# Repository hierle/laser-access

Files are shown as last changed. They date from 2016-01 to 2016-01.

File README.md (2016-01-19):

# laser-access

An access system for a laser cutter (or any other electric system), based on Arduino, ESP8266 Wifi and NFC reader and member cards.
Easy update of tag database via Wifi link to a central user db. This is running just fine for a while here at Fablab Munich :)

* [./eagle](https://github.com/hierle/laser-access/eagle/) &nbsp;&nbsp;&nbsp;&nbsp;&nbsp; PCB (eagle) files for custom shield
* [./housing](https://github.com/hierle/laser-access/housing/) &nbsp;&nbsp;&nbsp; DXF drawing for laser cut housing
* [./laser_access](https://github.com/hierle/laser-access/laser_access/) &nbsp; Arduino software

The software is running on an Arduino Mega 2560, packed with a "shield" (eagle files included),
holding breakout modules for RTC, NFC, Wifi (ESP8862-1), I2C-EEPROM and TFT touch display.

It's reading NFC (Mifare) cards dropped in, comparing the serial to a database in internal eeprom,
granting access to known serials only. If the tag serial number is found in eeprom database, then
- the 230V main relais of the laser cutter is turned on
- user name and phone number (both stored on the card) are displayed

If the dedicated "update card" is seen, the database (of allowed card serial numbers) is downloaded from a (Raspberry Pi) Wifi access point.

Internal 4k eeprom of the Mega board allows for up to 1000 users, external EEPROM holds up to 64kBytes log events.

Libraries used:

- https://github.com/adafruit/Adafruit_NFCShield_I2C
- https://github.com/adafruit/Adafruit-GFX-Library
- https://github.com/adafruit/Adafruit_ILI9341
- https://github.com/adafruit/Adafruit_STMPE610

Have fun :)

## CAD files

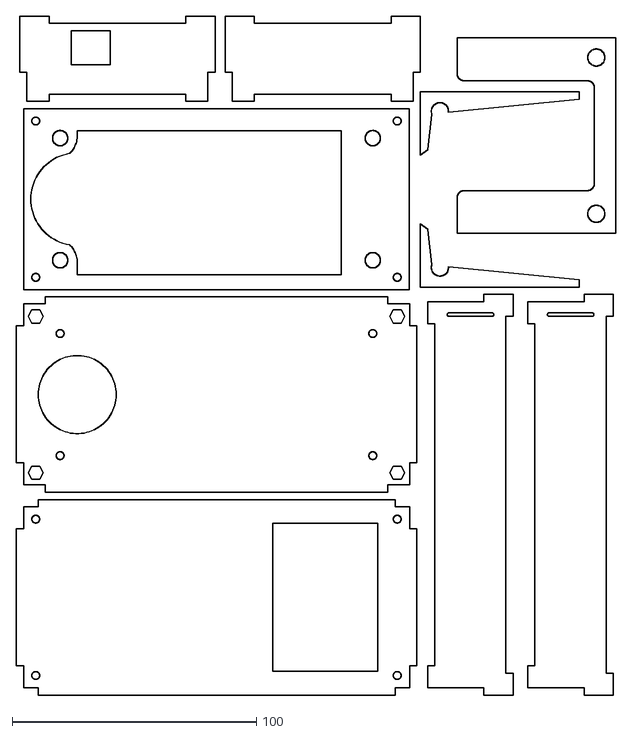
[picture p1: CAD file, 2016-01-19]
housing/laser-access-housing.dxf
245.5 x 278.0

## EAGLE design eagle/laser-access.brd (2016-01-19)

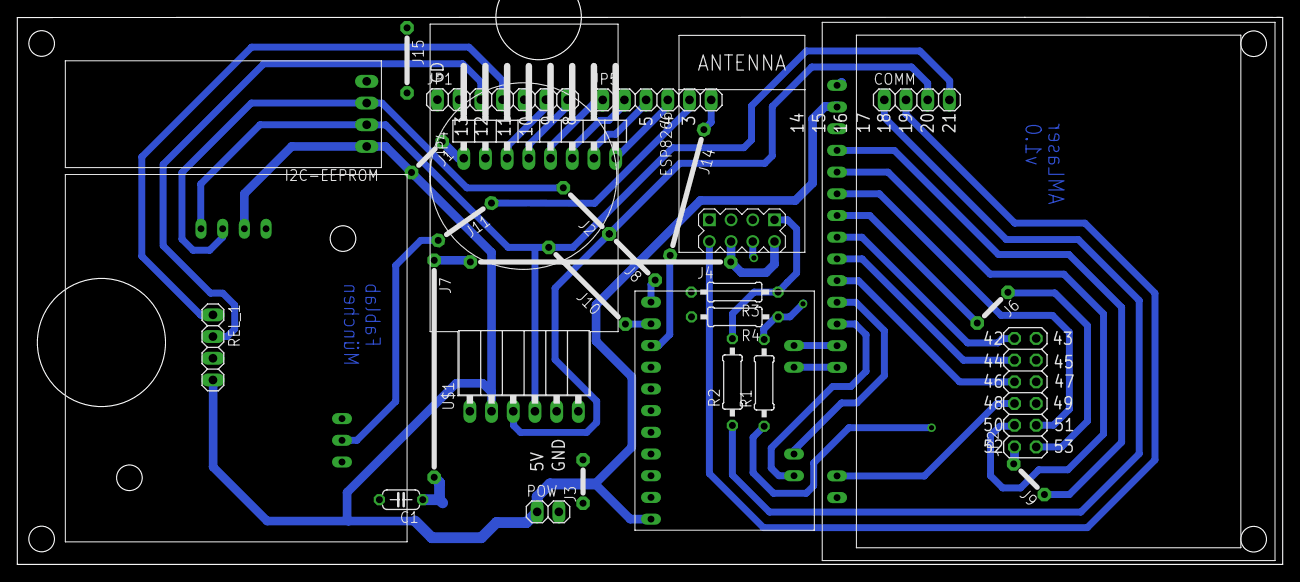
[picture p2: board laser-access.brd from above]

Board: 2 copper layers, 148.1 x 64.0 mm, 31 parts (1 on the bottom side), 32 nets.

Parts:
C1: C050-024X044
COMM: 1X04
ESP8266: WIRELESS-WIFI-ESP-01
I2C-EEPROM: I2C-EEPROM
IC2: LD117AS33TR; SOT223
J1, J3, J6, J9: J5MM; 05
J2, J8, J11, J15: J7MM; 07
J4: J30MM; 30
J7: J25MM; 25
J10: J12MM; 12
J14: J15MM; 15
JP1: 1X07
JP2: 2X06
JP4: 1X08/90
JP5: 1X06
POW: 1X02
R1, R2: 10k; 0207/10
R3, R4: 20k; 0207/10
REL_1: 1X04
U$1: I2C-RTC
U$3: TFT-2.4-SPI; TFT-SPI-2.4
U$4: I2C-NFC-V3
U$6: R-TOUCH

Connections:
42: JP2.12, U$3.DC
43: JP2.11, R1.1
44: JP2.10, U$3.RST
46: JP2.8, U$3.LITE
48: JP2.6, U$3.CCS
50: JP2.4, U$3.MISO
51: JP2.3, U$3.MOSI
52: J9.1, J9.2, JP2.2, U$3.CLK
53: J6.1, J6.2, JP2.1, U$3.CS
+3V3: C1.1, ESP8266.B2, ESP8266.D2, IC2.4, J4.1, J4.2, J7.1, J7.2
+5V: I2C-EEPROM.+5V, IC2.3, J1.1, J1.2, JP4.1, POW.1, REL_1.4, U$1.+5V, U$3.+5V, U$4.+5V, U$6.+5V
D2: J14.1, J14.2, JP5.6, U$6.IRQ
D3: J11.1, J11.2, JP5.5, U$4.IRQ
D4: JP4.8, JP5.4
D5: JP4.7, JP5.3
D6: JP4.6, JP5.2
D7: JP4.5, JP5.1
D8: JP1.7, JP4.4
D9: JP1.6, JP4.3
D11: JP1.4, REL_1.1
D12: JP1.3, REL_1.2
ESPRST: ESP8266.C2, R1.2, R4.1
ESP_RX: ESP8266.D1, R2.2, R3.1
GND: C1.2, ESP8266.A1, I2C-EEPROM.GND, IC2.1, J3.1, J3.2, J15.1, J15.2, JP1.1, JP4.2, POW.2, R3.2, R4.2, REL_1.3, U$1.GND, U$3.GND, U$4.GND, U$4.GND2, U$6.GND, U$6.MODE
RXD1: COMM.2, ESP8266.A2
SCL: COMM.4, I2C-EEPROM.SCL, J10.1, J10.2, U$1.SCL, U$4.SCL, U$6.SCL
SDA: COMM.3, I2C-EEPROM.SDA, J2.1, J2.2, J8.1, J8.2, U$1.SDA, U$4.SDA, U$6.SDA
TXD1: COMM.1, R2.1
X+: U$3.X+, U$6.X+
X-: U$3.X-, U$6.X-
Y+: U$3.Y+, U$6.Y+
Y-: U$3.Y-, U$6.Y-

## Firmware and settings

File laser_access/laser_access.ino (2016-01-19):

// 
// Name:      laser_access.ino
// Version:   0.1.4-github
// Date:      20160119
// Author:    A.Hierle <github@hierle.com>
// Purpose:   fablab laser access control
// Platform:  arduino mega2560


#include "laser_access.h"

#include <Wire.h>   // RTC and RTC-eeprom
#include <EEPROM.h> // internal eeprom
#include <SPI.h>    // SPI for TFT & SD card
#include <SD.h>     // SD card
#include <Adafruit_STMPE610.h>
#include <Adafruit_NFCShield_I2C.h>
#include <Adafruit_GFX_AS.h>
#include <Adafruit_ILI9341_AS.h>

#include <avr/pgmspace.h> // PROGMEM

time_t now;
time_t then;
//int wifi_status=0;
int enable=0;  // privileged enable mode: default off
time_t enable_start; // start enable mode
time_t power_start; // start ready mode
time_t dim_start; // start light/dim
time_t sense_last;

int counter=0;
int mode = 0;
int dim = 0;
unsigned long key_start=0;
uint8_t nfcid[]  = { 0, 0, 0, 0, 0, 0, 0 };
uint8_t lastid[] = { 0, 0, 0, 0 };
//unsigned long nfctag;
user_t user;
char command[64];
int sense[] = { -1, -1, -1, -1, -1, -1 };

uint8_t keya[6] = { 0xFF, 0xFF, 0xFF, 0xFF, 0xFF, 0xFF }; // NFC card default key
uint8_t keyf[6] = { 0x11, 0x22, 0x33, 0x44, 0x55, 0x66 }; // NFC card custom key, CHANGE!!!


// TFT
Adafruit_ILI9341_AS tft = Adafruit_ILI9341_AS(TFT_CS, TFT_DC, -1);
// Touch
Adafruit_STMPE610 touch = Adafruit_STMPE610();
// NFC
Adafruit_NFCShield_I2C nfc(NFC_IRQ, NFC_RESET);


//
// setup, running once, after reset
//
void setup() {
  
  // set default mode: power off
  mode = MODE_OFF;

  // power relais : LOW => ON , HIGH => OFF
  pinMode(PIN_POWER, OUTPUT);
  digitalWrite(PIN_POWER,HIGH);

  // esp reset line
  pinMode(PIN_ESP_RESET, OUTPUT);

  // init sense pins as input
  pinMode(SENSE_0, INPUT);
  pinMode(SENSE_1, INPUT);
  pinMode(SENSE_2, INPUT);
  pinMode(SENSE_3, INPUT);
  pinMode(SENSE_4, INPUT);

  // init I2C
  Wire.begin();

  write_log("booting");

  // init serial PC
  //Serial.begin(9600);
  Serial.begin(115200);
  Serial.println();
  Serial.println(F("booting ..."));
  
  Serial.print(F("init ESP8266..."));
  // init serial to wifi module
  //Serial1.begin(9600);
  Serial1.begin(115200);
  // 500?1000
  //Serial1.setTimeout(1000);
  // reset
  reset_wifi();
  
  Serial.println(F("ok"));

  // get time from DS3232 RTC
  get_time(&now);

  // dim off tft backlight
  analogWrite(PIN_TFT,200);
  get_time(&dim_start);
  dim=1;

  // start tft, blank black
  //tft.begin();
  tft.init();
  //tft.fillScreen(ILI9341_BLACK);
  tft.fillScreen(ILI9341_WHITE);

  if (! touch.begin(I2C_TOUCH_ADDR)) {
    Serial.println(F("touch controller not found!"));
    while(1);
  }
  //Serial.println(F("Waiting for touch sense"));


  // NFC
  Serial.print(F("init NFC controller..."));
  nfc.begin();
  //nfc.setPassiveActivationRetries(0x01);
  nfc.setPassiveActivationRetries(0x05);
  nfc.SAMConfig();
  Serial.println(F("ok"));

  // default: power OFF
  power_on(0);

  // init finished
  Serial.println(F("boot done!"));


  //
  // ONLY ONCE: set root pw ... has changed anyway :)
  //write_enable_pw("itchyiktestus");
  //
  // ONLY ONCE: set date/time
  //time_t n={22,10,0,2016,1,19};
  //set_time(n);

}
// end of setup



//
// the loop over and over
//
void loop() {


  int i;
  int bytesrec=0;
  int msglen=63;
  char usbmsg[msglen];
  char wifimsg[msglen];
  char buffer[16];
  uint16_t x, y;
  uint8_t z;
  
  memset(usbmsg,0,msglen); 
  memset(wifimsg,0,msglen); 

  // get time from rtc
  get_time(&now);
  // TODO: check for dead rtc ... too many things depend on it

  // update time display, once per minute
  if(now.minute!=then.minute) {
    //get_time(&then);
    memcpy((void *)&then,(void *)&now,sizeof(now));
    print_tft_time();
  }

  // update senses every 5 seconds
  if(mode==MODE_ON) {
    if (time_diff(now,sense_last)>5) {
      print_tft_sense();
      get_time(&sense_last);
    }
  }

  // enable mode expired?
  //if (time_diff(now,enable_start)>ENABLE_TIMEOUT) { enable=0; Serial.println("enable timeout reached ... disabling privileged mode."); }
  if(enable==1) {
    if (time_diff(now,enable_start)>ENABLE_TIMEOUT) {
      enable=0; 
      Serial.println(F("enable timeout reached ... disabling privileged mode."));
      write_log("enable off (timeout)");
    }
  }

  // dim timeout  
  if(dim==1) {
    if (time_diff(now,dim_start)>DIM_TIMEOUT) {
      analogWrite(PIN_TFT,10);
      dim=0;
    }
  }
  
  // touched
  if (touch.touched()) {
    analogWrite(PIN_TFT,200);
    get_time(&dim_start);
    dim=1;
    /**
    // read x & y & z;
    while (! touch.bufferEmpty()) {
      touch.readData(&x, &y, &z);
    }
    **/
    touch.writeRegister8(STMPE_INT_STA, 0xFF); // reset all ints
    delay(10);
  }

  if(mode==MODE_ON) {
    if (time_diff(now,power_start)>CARD_TIMEOUT) {
      mode=MODE_CARD;
      print_tft_power(2);
      //Serial.println(F("card timeout reached, re-validating card."));
    }
  }
  // timeout re-reading card
  if((mode==MODE_ON)||(mode==MODE_CARD)) {
    if (time_diff(now,power_start)>OFF_TIMEOUT) {
      power_on(0);
      Serial.println(F("power off (card timeout)"));
      write_log("power off");
    }
  }
  
  // read NFC tag
  if ((mode == MODE_CARD)||(mode == MODE_OFF)) {
    // nfc card detected?
    uint8_t success = 0;
    uint8_t nfclen;  // length of nfc id

    success = nfc.readPassiveTargetID(PN532_MIFARE_ISO14443A, nfcid, &nfclen);
    if (success) {
      handle_nfc(nfcid);
      //delay(100);
    } // success
    //Serial.println(" failed.");
  } //mode

  
  // serial (USB) from PC/user
  if(Serial.available()) {
    bytesrec = Serial.readBytes(usbmsg,msglen);
    handle_usb(usbmsg);
  }

  // serial from Wifi
  if(Serial1.available()) {
    bytesrec = Serial1.readBytes(wifimsg,msglen);
    handle_wifi(wifimsg);
  }
  
  delay(100);
}
// end of main loop





//
// functions
//


void reset_wifi() {
  // reset esp
  digitalWrite(PIN_ESP_RESET,LOW);
  //delay(350);
  //delay(800);
  delay(2000);
  digitalWrite(PIN_ESP_RESET,HIGH);
  //delay(2000);

  return;
}

//
// import access db via wifi
//
void import_wifi() {
  //
  // TODO: loop thru pages ...
  //
  int msglen=64;
  char msg[msglen];
  int bytesrec=0;
  user_t user;
  tag_t tag;
  char buffer[64];
  tag_t array[100];
  unsigned long id;
  int ac=0;
  int i;
  int page;
  int imported=0;
  String cmd;

  Serial.println(F("importing user db..."));
  write_log("importing user db...");

  tft.fillRect(0, 55, 310, 144, ILI9341_WHITE);

  tft.setTextColor(ILI9341_BLACK);
  tft.setRotation(3);
  sprintf(buffer,"%s","importing user db...");
  tft.drawString(buffer,20,80,4);

  // AT+CIPSTART="TCP","192.168.10.11",80
  //cmd = "AT+CIPSTART=\"TCP\",\"";  
  //cmd += "192.168.10.11";
  //cmd += "\",80";
  cmd = F("AT+CIPSTART=\"TCP\",\"192.168.10.11\",80");

  Serial1.println(cmd);  //send command to device

  delay(1000);  //wait a little while for 'Linked' response - this makes a difference
  if(Serial1.find("CONNECT")) {
    Serial.println(F("connected to server at 192.168.10.11"));
    sprintf(buffer,"%s","connected");
    tft.drawString(buffer,20,110,2);
  }
  else {
    Serial.println(F("'CONNECT' response not received"));
    sprintf(buffer,"%s","could not connect :(");
    tft.drawString(buffer,20,110,2);
  }

  delay(1000);
  
  // sequence ?page=1...10
  cmd = F("GET /cgi-bin/access\?amlaser HTTP/1.1\r\nHost: 192.168.10.11\r\n\r\n");
  Serial1.print(F("AT+CIPSEND="));
  Serial1.println(cmd.length());

  delay(200);

  //if(Serial1.find(">"))    //prompt offered by esp8266
  if(Serial1.find("OK")) {  //prompt offered by esp8266
    Serial.println(F("sending GET request..."));  //a debug message
    sprintf(buffer,"%s","sending GET request...");
    tft.drawString(buffer,20,125,2);
    Serial1.println(cmd);  //this is our http GET request
  }
  else {
    Serial1.println(F("AT+CIPCLOSE"));  //doesn't seem to work here?
    Serial.println(F("no '>' prompt received after AT+CPISEND"));
  }

  while (Serial1.find("ACCESS|")) {
    //if(Serial1.available()) {
    //bytesrec = Serial1.readBytes(msg,msglen);
    memset(msg,0,msglen);
    bytesrec = Serial1.readBytes(msg,10);
      
    sscanf(&msg[2],"%lx",(long *)&id);
    array[ac].b[3] = (id & 0xFF);
    array[ac].b[2] = ((id >> 8) & 0xFF);
    array[ac].b[1] = ((id >> 16) & 0xFF);
    array[ac].b[0] = ((id >> 24) & 0xFF);
    ac++;
  }    

  sprintf(buffer,"%d users received",ac);
  Serial.println(buffer);
  tft.drawString(buffer,20,140,2);
  write_log(buffer);

  for (i=0;i<ac;i++) {
    if(add_tag(array[i])==0) { imported++; }
  }

  sprintf(buffer,"%d new users imported",imported);
  Serial.println(buffer);
  tft.drawString(buffer,20,155,2);

  write_log(buffer);
  
  Serial1.println(F("AT+CIPCLOSE"));  
  delay(250);
  if(Serial1.find("OK")) {
    sprintf(buffer,"%s","connection closed.");
    tft.drawString(buffer,20,170,2);
  }

  //sprintf(buffer,"total: %d users imported",imported);
  //Serial.println(buffer);
  //tft.drawString(buffer,20,170,2);

   delay(3000);
} 
  

// user help (w/ and w/o enable)
void print_help() {
  time_t now;
  int secondsleft=0;
  
  Serial.println("");
  Serial.print(FIRMWARE);
  Serial.print(F(" v"));
  Serial.println(VERSION);
  Serial.println("");
  if(enable==1) {
    get_time(&now);
    secondsleft = ENABLE_TIMEOUT - time_diff(now,enable_start);
    Serial.println(F("available commands (enable mode):"));
    Serial.println("");
    Serial.println(F("addtag <nfctag>          : add nfc tag (4 byte id FFFFFFFF in hex) plus pin"));
    Serial.println(F("chpw <old_pw> <new_pw>   : change enable (privileged) mode password")); 
    Serial.println(F("cleardb                  : wipe out user db in eeprom"));
    Serial.println(F("clearlog                 : wipe out logs"));
    Serial.println(F("date                     : print current date/time"));
    Serial.println(F("deltag <nfctag>          : delete nfc tag (4 byte id FFFFFFFF in hex) (TODO)"));
    Serial.print  (F("disable                  : end enable mode ... "));Serial.print(secondsleft);Serial.println(F(" seconds left"));
    Serial.println(F("import                   : import access db via wifi"));
    Serial.println(F("list                     : list allowed nfc tags"));
    Serial.println(F("log                      : show log entries"));
    Serial.println(F("resetwifi                : reset esp wifi"));
    Serial.println(F("wifi <command>           : send command to wifi module, e.g. AT :)"));
    Serial.println(F("h (or ?)                 : this help"));
    //Serial.println(F("testlog <count>          : test log"));
    Serial.println("");
  }
  else { // free 4 all commands
    Serial.println(F("available commands:"));
    Serial.println("");
    Serial.println(F("h (or ?)                 : this help"));
    Serial.println(F("log                      : list log entries"));
    Serial.println(F("date                     : print current date / time"));
    Serial.println(F("enable <enable pw>       : switch to privileged mode")); 
    Serial.println("");
  }
}  



// handle serial from PC
void handle_usb(char * msg) {
  int i;
  
  // help
  if((msg[0]=='h')||(msg[0]=='?')) { print_help(); return; }
  // date
  if(strncmp(msg,"date",4)==0) { print_date(); return; }
  // log
  if(strncmp(msg,"log",3)==0) { read_log(); return; }
  // switch to enable mode
  if(strncmp(msg,"enable",6)==0) { start_enable(msg); return; }

  // for the rest of the user commmands, we need to be in enable mode
  if(enable!=1) { Serial.println(F("unknown command, try \"help\"")); return; }

  // add tag
  if(strncmp(msg,"addtag",6)==0) { if(add_nfctag(&msg[7])==0) { Serial.println(F("added.")); } return; }
  // change enable password
  if(strncmp(msg,"chpw",4)==0) { Serial.println(F("changing enable password.")); change_enable_pw(msg); return; }
  // clear eeprom user db
  if(strncmp(msg,"cleardb",7)==0) { clear_db(EE_USER); return; }
  // clear logs
  if(strncmp(msg,"clearlog",8)==0) { clear_log(); return; }
  // reset esp wifi
  if(strncmp(msg,"resetwifi",9)==0) { reset_wifi(); return; }
  // import users via wifi
  if(strncmp(msg,"import",6)==0) { import_wifi(); return; }
  // wifi
  if(strncmp(msg,"wifi",4)==0) { Serial1.println(&msg[4]); return; }
  // list
  if(strncmp(msg,"list",4)==0) { list_all(); return; }
  // leave enable mode
  if(strncmp(msg,"disable",7)==0) { Serial.println(F("leaving privileged mode.")); write_log("enable off"); enable=0; return; }

  // DEBUG
  // short (end of) log
  //if(strncmp(msg,"sl",2)==0) { short_log(); return; }
  // test log
  //if(strncmp(msg,"tl",2)==0) { test_log(&msg[3]); return; }
  // dump log
  //if(strncmp(msg,"dl",2)==0) { dump_log(&msg[3]); return; }


  // if we reached here ... it's an unsupported/unknow command ;)
  Serial.println(F("unknown command, try \"help\""));
  //Serial.println(msg);

}



// handle message from wifi
void handle_wifi(char * msg) {
  int i;
  char buf[64];

  // save wifi status
  //if(strstr(msg,"OK")!=NULL) { wifi_status=0; }
  //if(strstr(msg,"ERROR")!=NULL) { wifi_status=-1; strncpy(wifi_error,msg,sizeof(wifi_error)); }

  //if(strlen(msg) < 2) { return; }

  // debug
  Serial.print(F("debug message from wifi: ->")); Serial.print(msg); Serial.println(F("<-"));

}





//
// handle nfc card
void handle_nfc(uint8_t * nfcid) {
  int i;
  int block; // 1-63
  char buffer[64];
  time_t now;
  uint8_t success;
  uint8_t uidLength = 4;
  uint8_t data[16];
  tag_t tag;

  // update card (hard coded)
  if ((nfcid[0]==0xAA)&&(nfcid[1]==0xBB)&&(nfcid[2]==0xCC)&&(nfcid[3]==0xDD)) { 
    import_wifi();
    return;
  }

  // lookup id in db ...
  for (i=0;i<4;i++) { tag.b[i] = nfcid[i]; }
  if(get_id(tag) < 0) { // tag not on db
    // same unknown card
    if ((nfcid[0]==lastid[0])&&(nfcid[1]==lastid[1])&&(nfcid[2]==lastid[2])&&(nfcid[3]==lastid[3])) { delay(2000); return; }
    Serial.println(F("error: card not on db"));
    sprintf(buffer,"nfc tag 0x%02X%02X%02X%02X not on db",nfcid[0],nfcid[1],nfcid[2],nfcid[3]);
    write_log(buffer);
    // set lastid
    for (i=0;i<4;i++) { lastid[i]=nfcid[i]; }
    delay(1000);
    return;
  }
  // tag is on db
  // same known card again
  if((mode==MODE_ON)||(mode==MODE_CARD)) {
    if ((nfcid[0]==lastid[0])&&(nfcid[1]==lastid[1])&&(nfcid[2]==lastid[2])&&(nfcid[3]==lastid[3])) {
      mode = MODE_ON;
      get_time(&power_start);
      print_tft_power(1);
      return;
    }
  }

  if(read_card(nfcid)==0) {
    // Power ON
    power_on(1);
    get_time(&power_start);
    sprintf(buffer,"power on for 0x%02X%02X%02X%02X",nfcid[0],nfcid[1],nfcid[2],nfcid[3]);
    write_log(buffer);
    Serial.println(buffer);
    // set lastid
    for (i=0;i<4;i++) { lastid[i]=nfcid[i]; }
    print_tft_user();
  }
  
}




//
// read nfc card
//
int read_card(uint8_t * nfcid) {
  int i;
  int block; // 1-63
  char buffer[64];
  //time_t now;
  uint8_t success;
  uint8_t uidLength = 4;
  uint8_t data[16];
  tag_t tag;
  uint8_t data2[64];
  char data3[64];

  memset((void *)&user,0,sizeof(user));

  // name
  block = 8;
  // auth
  success = nfc.mifareclassic_AuthenticateBlock(nfcid, uidLength, block, 0, keyf);
  if (!success) { Serial.print(F("error: can not authenticate block ")); Serial.println(block,DEC); return(-1); }
  // read
  success = nfc.mifareclassic_ReadDataBlock(block, data);
  if (!success) { Serial.print(F("error: can not read block ")); Serial.println(block,DEC); return(-2); }
  //memset(user.name,0,33);
  memcpy(user.name,(const char *)data,16);
  //strncpy(user.name,(const char *)data,strlen((const char *)data));
  delay(250);
  // name part 2
  block = 9;
  // already auth
  // read
  success = nfc.mifareclassic_ReadDataBlock(block, data);
  if (!success) { Serial.print(F("error: can not read block ")); Serial.println(block,DEC); return(-2); }
  memcpy(&user.name[16],(const char *)data,16);
  delay(250);

  // phone
  block = 10;
  // already auth
  // read
  success = nfc.mifareclassic_ReadDataBlock(block, data);
  if (!success) { Serial.print(F("error: can not read block ")); Serial.println(block,DEC); return(-2); }
  strncpy(user.phone,(const char *)data,strlen((const char *)data));
  delay(250);

  // serial
  block = 13;
  // auth
  success = nfc.mifareclassic_AuthenticateBlock(nfcid, uidLength, block, 0, (uint8_t *)keyf);
  if (!success) { Serial.print(F("error: can not authenticate block ")); Serial.println(block,DEC); return(-1); }
  // read
  success = nfc.mifareclassic_ReadDataBlock(block, data);
  if (!success) { Serial.print(F("error: can not read block ")); Serial.println(block,DEC); return(-2); }
  memcpy(user.serial,(const char *)data,4);

  // check for tampered serial
  for (i=0;i<4;i++) {
    if(user.serial[i] != nfcid[i]) {
      // card tampered !!!
      sprintf(buffer,"card tampered : 0x%02X%02X%02X%02X",nfcid[0],nfcid[1],nfcid[2],nfcid[3]);
      Serial.println(buffer);
      write_log(buffer);
      return(-3);
    }
  }

  // write last use timestamp to card
  block = 14;
  // already auth
  // write
  memset(data, 0, sizeof(data));
  //snprintf ((char *)data,sizeof(data),"%02d:%02d %04d%02d%02d",now.hour,now.minute,now.year,now.month,now.day);
  snprintf ((char *)data,sizeof(data),"%04d%02d%02d %02d:%02d",now.year,now.month,now.day,now.hour,now.minute);
  success = nfc.mifareclassic_WriteDataBlock (block, data);
  if (!success) { Serial.print(F("error: can not write block ")); Serial.println(block,DEC); return(-2); }

  return(0);

}


//
// print user name+phone+serial to tft
//
void print_tft_user() {
  char ser[16];

  tft.fillRect(0, 55, 310, 144, ILI9341_WHITE);
  tft.setTextColor(ILI9341_BLACK);
  tft.setRotation(3);
  // name
  tft.drawString(user.name,20,80,4);
  // phone
  tft.drawString(user.phone,20,120,4);
  // serial
  sprintf (ser,"0x%02X%02X%02X%02X",user.serial[0],user.serial[1],user.serial[2],user.serial[3]);
  tft.drawString(ser,20,160,4);
}





// convert hex to decimal ... and vice versa
byte __attribute__ ((noinline)) dec2hex(byte val) {
  return ((val/10*16) + (val%10));
}
byte __attribute__ ((noinline)) hex2dec(byte val) {
  return ( (val/16*10) + (val%16) );
}


// get time/date from RTC via I2C
void get_time (time_t *now ) {
  Wire.beginTransmission(I2C_RTC_ADDR);
  Wire.write(0); // set DS3232 register pointer to 0x00
  Wire.endTransmission();
  Wire.requestFrom(I2C_RTC_ADDR, 7); 
  now->second = hex2dec(Wire.read() & 0x7f);
  now->minute = hex2dec(Wire.read());
  now->hour   = hex2dec(Wire.read() & 0x3f);
  Wire.read(); // dayOfWeek
  now->day    = hex2dec(Wire.read());
  now->month  = hex2dec(Wire.read());
  now->year   = 2000 + hex2dec(Wire.read());

  // debug
//  char date_s[32];
//  sprintf(date_s,"DATE:   %02d:%02d:%02d   %02d.%02d.%04d",now->hour,now->minute,now->second,now->day,now->month,now->year);
//  Serial.println(date_s);
}


// set RTC date/time (needed only once in batteries lifetime)
void set_time(time_t now) {
  Wire.beginTransmission(I2C_RTC_ADDR);
  Wire.write(0); // set DS3232 register pointer to 00h
  Wire.write(dec2hex(now.second));
  Wire.write(dec2hex(now.minute));
  Wire.write(dec2hex(now.hour));  // set 24 hour format (bit 6 == 0)
  Wire.write(4); // day of week 1=sun ... 7=sat
  Wire.write(dec2hex(now.day));
  Wire.write(dec2hex(now.month));
  Wire.write(dec2hex(now.year-2000)); 
  Wire.endTransmission();  
/**
  00h - seconds
  01h - minutes
  02h - hours
  03h - day of the week. The convention is to use 1 for Sunday, 2 for Monday, etc. 
  04h - date (1~31)
  05h - month (1~12)
  06h - year (00~99). 
**/
}


// time diff: difference between two times 
// ... just as 7-3 -> int_diff(7,3) = 4 > 0
// now after  then ->  >0
// now before then ->  <0
long time_diff(time_t now, time_t then) {
  int h,m,s,d;
  long diff;
  d=now.day-then.day;
  h=now.hour-then.hour;
  m=now.minute-then.minute;
  s=now.second-then.second;
  //diff = 3600L*(now.hour-then.hour)+60*(now.minute-then.minute)+now.second-then.second;
  diff = 3600L*h+60*m+s;
  if(d != 0) { diff += 86400; } // day rollover
  return(diff);
}





// find tag entry, return id (int) (or -1 if not found)
int get_id(tag_t tag) {
  unsigned int id,first,next;
  unsigned int counter=0;
  int i=0;
  byte x[4];
  unsigned int addr=0;

  // next tag number
  next = ((EEPROM.read(EE_NEXT)<<0) & 0xFF) + ((EEPROM.read(EE_NEXT+1)<<8) & 0xFFFF);
  if(next==0) { return(-1); }
  for (id=0;id<next;id++) {
    // addr[0123]
    addr=EE_USER+4*id;
    // check id
    for (i=0;i<4;i++) {
      if (EEPROM.read(addr+i) != tag.b[i]) { break; }
      /**
      x[i]=EEPROM.read(addr+i);
      Serial.print("get_id: id:");
      Serial.print(id,DEC);
      Serial.print(" i:");
      Serial.print(i,DEC);
      Serial.print(" x: 0x");
      Serial.print(x[i],HEX);
      Serial.print(" tag: 0x");
      Serial.print(tag.b[i],HEX);
      Serial.println();
      if (x[i] != tag.b[i]) { break; }
      **/
    }
    if(i==4) { return(id); }
  }
  return(-1);
}
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

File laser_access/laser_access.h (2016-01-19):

//
// laser_access.h
//


#define VERSION F("0.1.4-github")
#define FIRMWARE F("FabLab laser access control")


#define CARD_TIMEOUT     10  // after 10 seconds try to re-validate card
#define OFF_TIMEOUT      20  // after 10+10==20 seconds w/o valid card: power off
#define DIM_TIMEOUT     300  // after 300 seconds dim tft down
#define ENABLE_TIMEOUT  300  // after 300 seconds disable privileged mode

// Power PINs
#define PIN_POWER     12  // power relais
#define PIN_CHAIN     11  // unused

// Sense PINs
#define SENSE_0    4  // service hatches
#define SENSE_1    5  // front hatch
#define SENSE_2    6  // chiller
#define SENSE_3    7  // compressed air
#define SENSE_4    8  // reserved
#define SENSE_5    9  // reserved


// ESP8266 reset pin
#define PIN_ESP_RESET 43

// PWM PINs
//#define PIN_INT_LED   13
#define PIN_TFT       46  // pwm TFT backlight
#define FREQ 50000    // pwm frequency (in Hz)

// mode
#define MODE_OFF          0  // power off
#define MODE_ON           1  // power on
#define MODE_CARD         2  // power still on, re-validating card
#define MODE_MAINTENANCE  99 // 

// I2C addresses
#define I2C_RTC_ADDR     0x68 // 104 RTC
#define I2C_EE_ADDR      0x54 // 80 64k eeprom 4 logging
#define I2C_TOUCH_ADDR   0x41 // touch controller
#define I2C_NFC_ADDR     0x24 // useless here: set in adafruit_nfc library
//#define I2C_RTCEE_ADDR   0x50 // unused ?
//#define I2C__ADDR     0x78 // unused ?

//#define TFT_MISO 50
//#define TFT_MOSI 51
//#define TFT_CLK 52
//#define TFT_RST -1
#define TFT_DC  42
#define TFT_CS  53 // SS

//#define TFT_IRQ 3
#define SD_CS   48

#define NFC_IRQ    3
#define NFC_RESET -1  // Not connected

//#define CTRL_Z 26

//#define byte unsigned char
//#define byte uint8_t

// internal eeprom offsets
#define EE_MASTER 0
#define EE_ENABLE_LEN       80  // length of enable pw stored 80
#define EE_ENABLE_MAX_LEN   12  // max 12 digits (81...93)
#define EE_ENABLE_PW        81  // store enable pw in 81...93
// first user  @#96 ...leaves room for 1000 (id(4Byte) users
#define EE_NEXT             94  // (94 + 95) store next=last user id here
#define EE_USER             96  // start of user db here
#define EE_MAX            4096  // 4k internal eeprom

//#define EE_LOG_MIN       0  // log space from here
//#define EE_LOG_MAX   32760  // log space till here
//#define EE_LOG_START_ADDR 32764  // (32764 + 32765) store start of logs here
//#define EE_LOG_END_ADDR   32766  // (32766 + 32767) store end of logs here
////#define EXT_EE_MAX       32768  // absolute maximum

#define EE_LOG_MIN       0  // log space from here
#define EE_LOG_MAX   65530  // log space till here
#define EE_LOG_START_ADDR 65532  // (65532 + 65533) store start of logs here
#define EE_LOG_END_ADDR   65534  // (65534 + 65535) store end of logs here
//#define EXT_EE_MAX       65536  // absolute maximum


// Color definitions
#define ILI9341_BLACK       0x0000      /*   0,   0,   0 */
#define ILI9341_NAVY        0x000F      /*   0,   0, 128 */
#define ILI9341_DARKGREEN   0x03E0      /*   0, 128,   0 */
#define ILI9341_DARKCYAN    0x03EF      /*   0, 128, 128 */
#define ILI9341_MAROON      0x7800      /* 128,   0,   0 */
#define ILI9341_PURPLE      0x780F      /* 128,   0, 128 */
#define ILI9341_OLIVE       0x7BE0      /* 128, 128,   0 */
#define ILI9341_LIGHTGREY   0xC618      /* 192, 192, 192 */
#define ILI9341_DARKGREY    0x7BEF      /* 128, 128, 128 */
#define ILI9341_BLUE        0x001F      /*   0,   0, 255 */
#define ILI9341_GREEN       0x07E0      /*   0, 255,   0 */
#define ILI9341_CYAN        0x07FF      /*   0, 255, 255 */
#define ILI9341_RED         0xF800      /* 255,   0,   0 */
#define ILI9341_MAGENTA     0xF81F      /* 255,   0, 255 */
#define ILI9341_YELLOW      0xFFE0      /* 255, 255,   0 */
#define ILI9341_WHITE       0xFFFF      /* 255, 255, 255 */
#define ILI9341_ORANGE      0xFD20      /* 255, 165,   0 */
#define ILI9341_GREENYELLOW 0xAFE5      /* 173, 255,  47 */
#define ILI9341_PINK        0xF81F




// non standard :) time_t
typedef struct {
  unsigned int hour;
  unsigned int minute;
  unsigned int second;
  unsigned int year;
  unsigned int month;
  unsigned int day;
  unsigned long unixtime;
} time_t;




// select * from users
// id|name|phone|tag|zugang|amlaser|zinglaser|ulti|ulti2|res1|res2|comment
// tag:
//     0xAABBCCDD
//     0| long(4B) |
typedef struct {
  unsigned int id;
  char name[33];
  char phone[32];
  unsigned char serial[4];
} user_t;


typedef struct {
  //unsigned long b[4];
  unsigned char b[4];
} tag_t;

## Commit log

2016-01-19 added eagle schematic and board files
    [laser-access.brd, laser-access.sch]
2016-01-19 added housing dxf
    [laser-access-housing.dxf]

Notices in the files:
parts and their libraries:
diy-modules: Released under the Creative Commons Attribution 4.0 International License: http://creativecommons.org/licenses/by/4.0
